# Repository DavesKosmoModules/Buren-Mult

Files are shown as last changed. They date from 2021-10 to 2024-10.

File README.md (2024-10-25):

# Buren-Mult

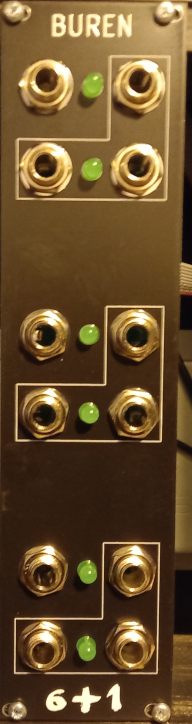
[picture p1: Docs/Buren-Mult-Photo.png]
Buren Photo


An active mult in Kosmo modular synth format

- 3 input 9 output active mult
- Normalized inputs can be 1 in 9 out, 3 in 3 outs or 2 in 3 out + 6 out
- Original concept was to allow patching of V/oct, Gate & velocity from a sequencer

Contained are schematics & gerber files for pcb fabrication of both electrical and front panel. This is sutiable for entry level however a basic level of electronics, soldering, fault finding, and some basic tools are required.

If you wish to edit in ki-cad the following dependencies are required

https://gitlab.com/rsholmes/Kosmo_panel
 
https://gitlab.com/rsholmes/aoKicad

[Schematic](/Docs/Buren-Mult-Schematic.pdf)

[BOM](Docs/Buren-Mult-BOM.pdf)

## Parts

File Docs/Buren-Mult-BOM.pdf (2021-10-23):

Id | Designator | Package | Quantity | Designation
| 1 C1,C2,C3,C4,C5,C6 | C_Disc_D3.0mm_W1.6mm_P2.50mm | | 6 0.1uF
| 2 C7,C8 | CP_Radial_D6.3mm_P2.50mm | | 2 10uF
| 3 D1,D2 | D_DO‐41_SOD81_P10.16mm_Horizontal | | 2 1N5817
| 4 D3,D4,D5,D6,D7,D8 | LED_D5.0mm | | 6 LED

5

| J1,J2,J3,J5,J6,J7,J8,J9,J10,J11,J1
| 2,J13 | Jack_6.35mm_PJ_629HAN | | 12 AudioJack2_SwitchT
| 6 J4 | Power_Header | | 1 Synth_power_2x5
| 7 R1,R6,R11 | R_Axial_DIN0207_L6.3mm_D2.5mm_P10.16mm_ | | 3 6M8

8

| R2,R3,R4,R5,R7,R8,R9,R10,R12,
| R13,R14,R15 | R_Axial_DIN0207_L6.3mm_D2.5mm_P10.16mm_ | | 12 1k
| 9 U1,U2,U3 | DIP‐14_W7.62mm_Socket_LongPads | | 3 TL074

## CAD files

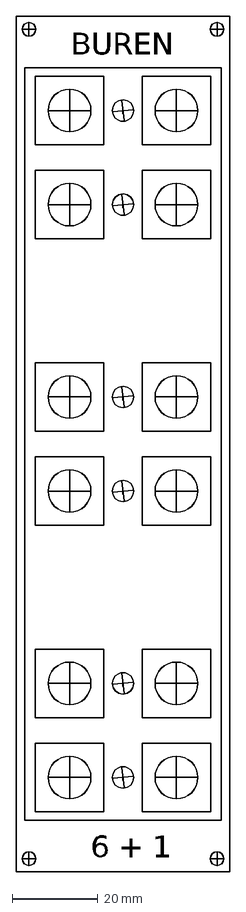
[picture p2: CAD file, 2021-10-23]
MultPlatesExport.dxf
6 + 1
BUREN

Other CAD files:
MultallPlates.dwg
MultPlatesExport.dwg

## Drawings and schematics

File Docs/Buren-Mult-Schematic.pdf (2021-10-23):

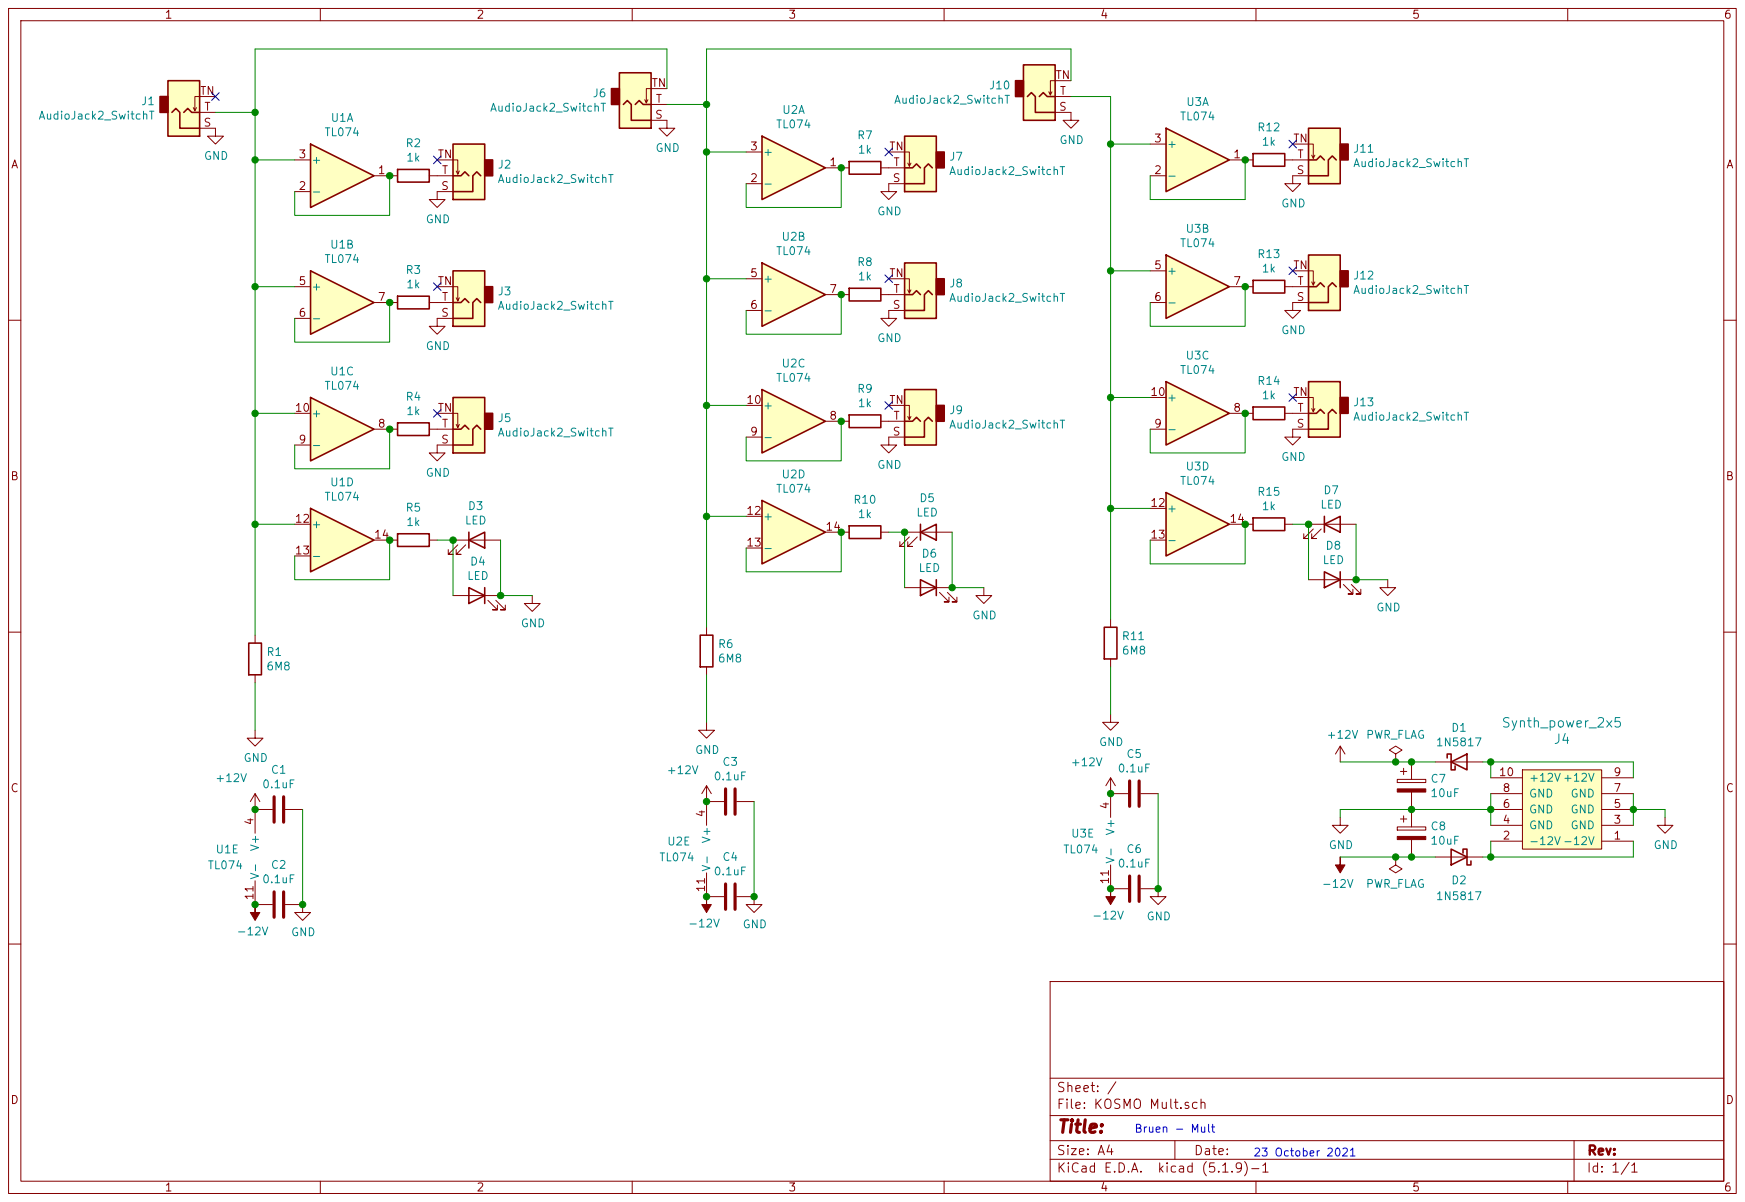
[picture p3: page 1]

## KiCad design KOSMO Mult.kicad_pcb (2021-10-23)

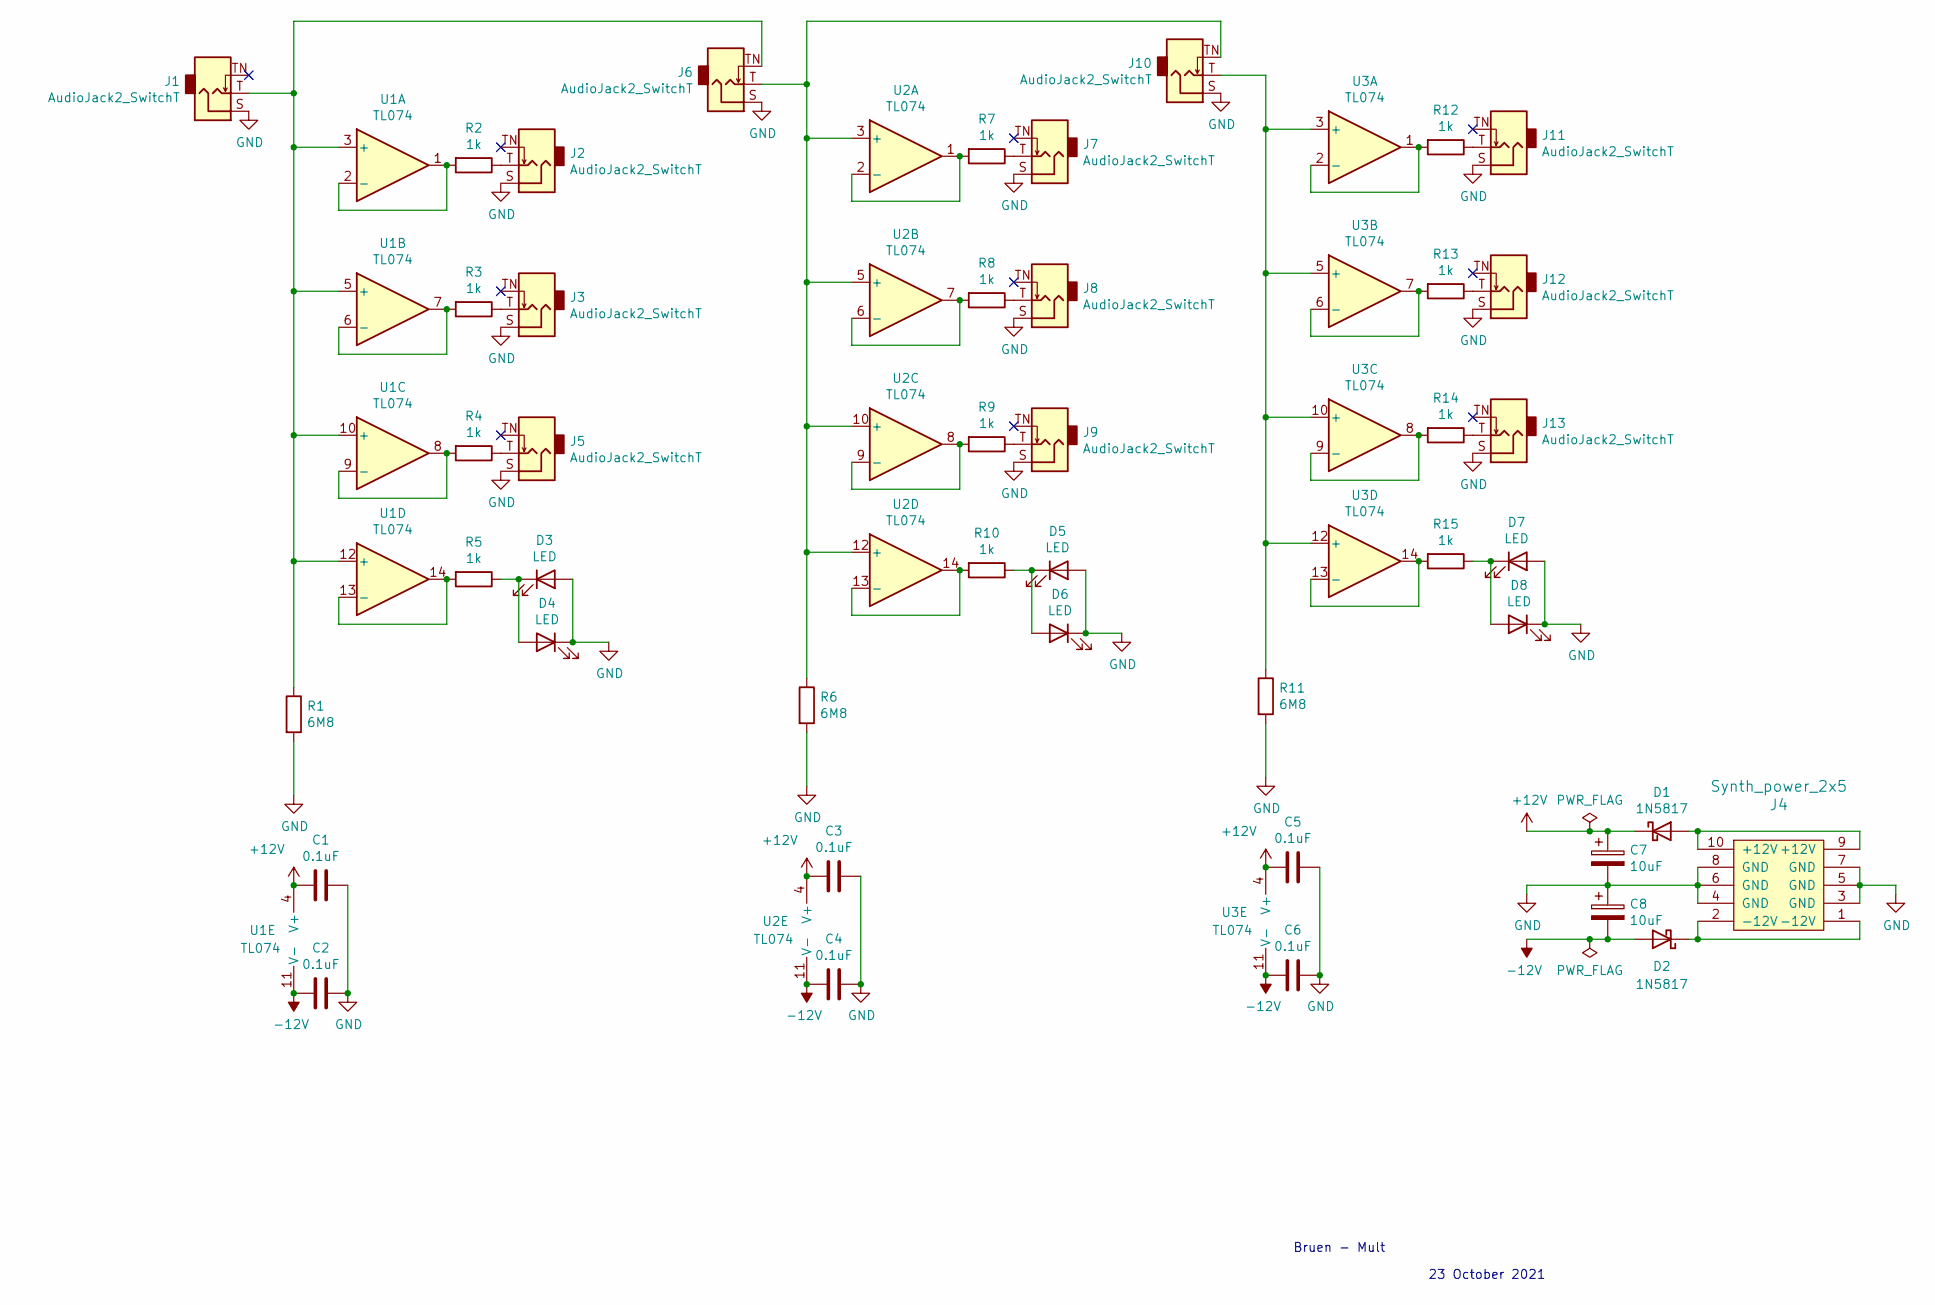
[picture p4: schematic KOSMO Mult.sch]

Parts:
C1, C2, C3, C4, C5, C6: 0.1uF; C_Disc_D3.0mm_W1.6mm_P2.50mm
C7, C8: 10uF; CP_Radial_D6.3mm_P2.50mm
D1, D2: 1N5817; D_DO-41_SOD81_P10.16mm_Horizontal
D3, D4, D5, D6, D7, D8: LED; LED_D5.0mm
J1, J2, J3, J5, J6, J7, J8, J9, J10, J11, J12, J13: AudioJack2_SwitchT; Jack_6.35mm_PJ_629HAN
J4: Synth_power_2x5; Power_Header
R1, R6, R11: 6M8; R_Axial_DIN0207_L6.3mm_D2.5mm_P10.16mm_Horizontal
R2, R3, R4, R5, R7, R8, R9, R10, R12, R13, R14, R15: 1k; R_Axial_DIN0207_L6.3mm_D2.5mm_P10.16mm_Horizontal
U1, U2, U3: TL074; DIP-14_W7.62mm_Socket_LongPads

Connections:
+12V: C1.2, C3.2, C5.2, C7.1, D1.1 (K), U1.4 (V+), U2.4 (V+), U3.4 (V+)
-12V: C2.2, C4.2, C6.2, C8.2, D2.2 (A), U1.11 (V-), U2.11 (V-), U3.11 (V-)
GND: C1.1, C2.1, C3.1, C4.1, C5.1, C6.1, C7.2, C8.1, D3.2 (A), D4.1 (K), D5.2 (A), D6.1 (K), D7.2 (A), D8.1 (K), J1.S, J2.S, J3.S, J4.3 (GND), J4.4 (GND), J4.5 (GND), J4.6 (GND), J4.7 (GND), J4.8 (GND), J5.S, J6.S, J7.S, J8.S, J9.S, J10.S, J11.S, J12.S, J13.S, R1.2, R6.2, R11.2
unnamed: D1.2 (A), J4.9 (+12V), J4.10 (+12V)
unnamed: D2.1 (K), J4.1 (-12V), J4.2 (-12V)
unnamed: D3.1 (K), D4.2 (A), R5.1
unnamed: D5.1 (K), D6.2 (A), R10.1
unnamed: D7.1 (K), D8.2 (A), R15.1
unnamed: J1.T, J6.TN, R1.1, U1.3 (+), U1.5 (+), U1.10 (+), U1.12 (+)
unnamed: J2.T, R2.1
unnamed: J3.T, R3.1
unnamed: J5.T, R4.1
unnamed: J7.T, R7.1
unnamed: J8.T, R8.1
unnamed: J9.T, R9.1
unnamed: J10.T, R11.1, U3.3 (+), U3.5 (+), U3.10 (+), U3.12 (+)
unnamed: J6.T, J10.TN, R6.1, U2.3 (+), U2.5 (+), U2.10 (+), U2.12 (+)
unnamed: J11.T, R12.1
unnamed: J12.T, R13.1
unnamed: J13.T, R14.1
unnamed: R2.2, U1.1, U1.2 (-)
unnamed: R3.2, U1.6 (-), U1.7
unnamed: R4.2, U1.8, U1.9 (-)
unnamed: R5.2, U1.13 (-), U1.14
unnamed: R7.2, U2.1, U2.2 (-)
unnamed: R8.2, U2.6 (-), U2.7
unnamed: R9.2, U2.8, U2.9 (-)
unnamed: R10.2, U2.13 (-), U2.14
unnamed: R12.2, U3.1, U3.2 (-)
unnamed: R13.2, U3.6 (-), U3.7
unnamed: R14.2, U3.8, U3.9 (-)
unnamed: R15.2, U3.13 (-), U3.14

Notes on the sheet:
Bruen - Mult
23 October 2021

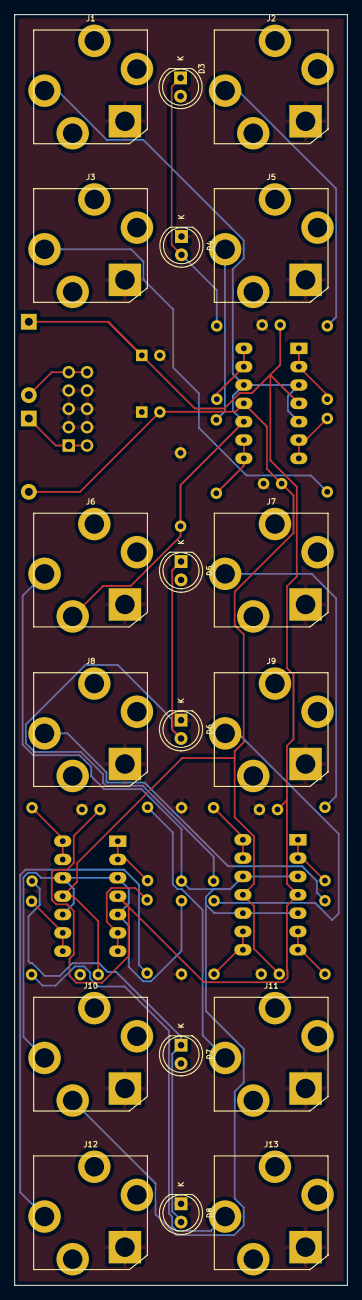
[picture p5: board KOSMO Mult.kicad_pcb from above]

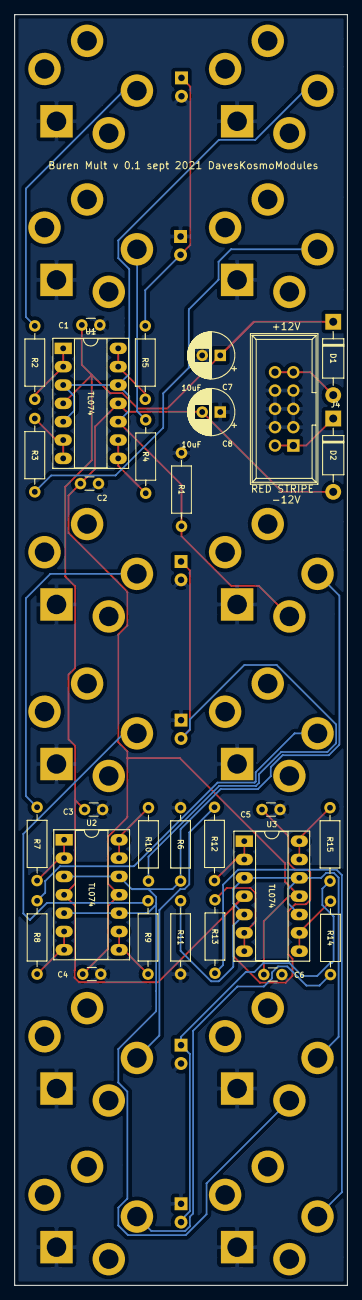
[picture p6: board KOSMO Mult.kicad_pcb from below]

Board: 2 copper layers, 46.1 x 176.0 mm, 47 parts (29 on the bottom side), 32 nets.
